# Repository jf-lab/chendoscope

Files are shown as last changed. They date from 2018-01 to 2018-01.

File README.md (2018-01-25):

# CHEndoscope Overview

Complete instructions on how to use the CHEndoscope, including assembly, surgery, behavioural protocols and data analysis can be in the [CHEndoscope protocols paper](https://www.biorxiv.org/content/early/2018/01/24/252205).

1. [Assembling your CHEndoscope](#assembling-your-chendoscope)
2. [Acquiring images with your CHEndoscope](#acquiring-images-with-your-chendoscope) 
	- [Installing acquisition code](#installation)
	- [Running the acquisition software](#running-the-acquisition-software)

3. Analysis of calcium imaging videos uses [CHEndoscope-minipipe](https://github.com/jf-lab/chendoscope-minipipe)

# Assembling your CHEndoscope
The CHEndoscope consists of 4 plastic components that can be 3D printed

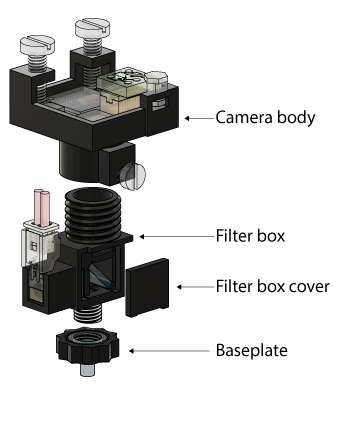
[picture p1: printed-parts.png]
3D printed components of the CHEndoscope


When printing these parts, we recommend a print resolution of at most 100μm (50μm works best in our hands). Our lab has experimented with various FDM, SLA and material jetting printers, and find that SLA printers such as the Formlabs Form2 render best results. FDM printers often lack the resolution required to render the fine threads and internal details of several CHEndoscope parts. In addition to print resolution, make sure the material you are printing with does not fluoresce or otherwise interfere with the imaging path when exposed to 470nm or 535nm light.

Download CHEndoscope [STL files](./STLs) for 3D printing, or [STEP files](./STEP-files) if you want to modify the base CHEndoscope design.

# Acquiring images with your CHEndoscope

In order to capture images from the CHEndoscope, you will need to install acquisition software that interfaces with the CHEndoscope's Ximea USB camera. This code is compatible with Linux and Windows systems.

## Installation 

[For Windows](acquisition-install-windows.md)

## Running the acquisition software

1. Open a new cmd window
    - `cd [path for storing video files]`
    - `python "path\to\vid.py"`

2. To change gains/exposure etc:
    - Open a second cmd window and run 
		`ncat -u 127.0.0.1 6557`
    - Then type for example:
		`[set_gain 10]`

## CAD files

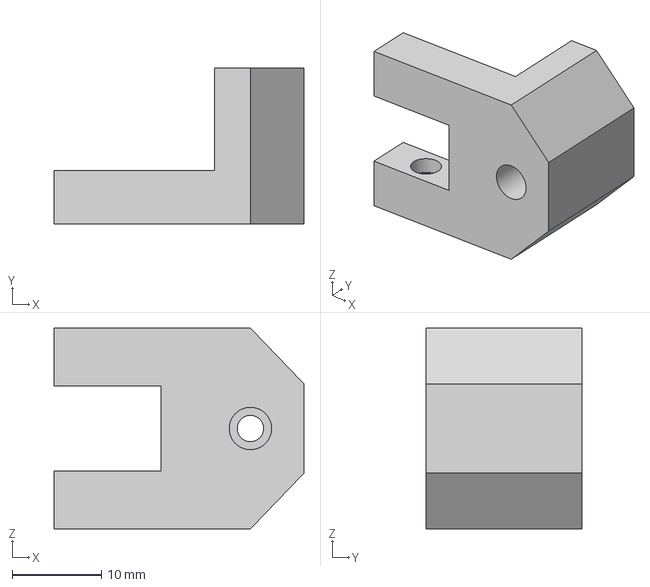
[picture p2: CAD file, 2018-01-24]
STEP-files/Stereotax clamp.step
28.0 x 17.5 x 22.5 mm

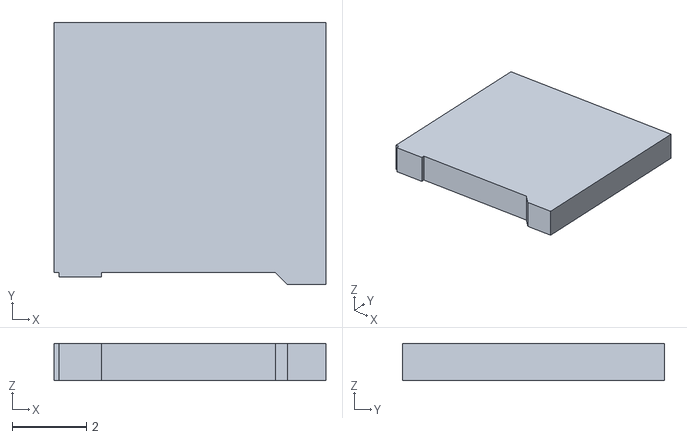
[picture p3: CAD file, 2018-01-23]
STLs/Filter box cover.stl
7.35 x 7.07 x 1.00

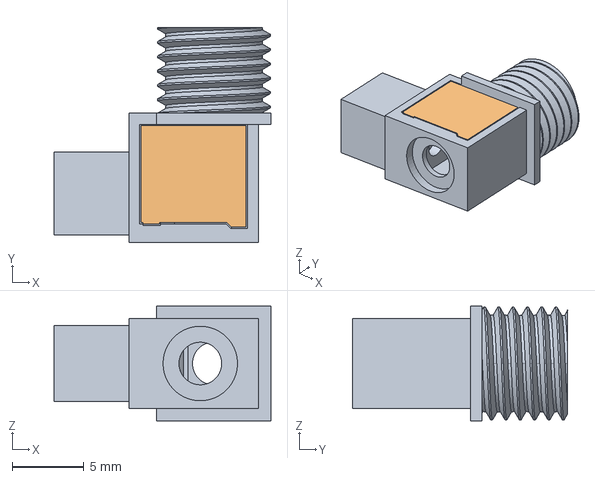
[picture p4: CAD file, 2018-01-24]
STEP-files/Filter box.step
15.2 x 15.0 x 8.00 mm

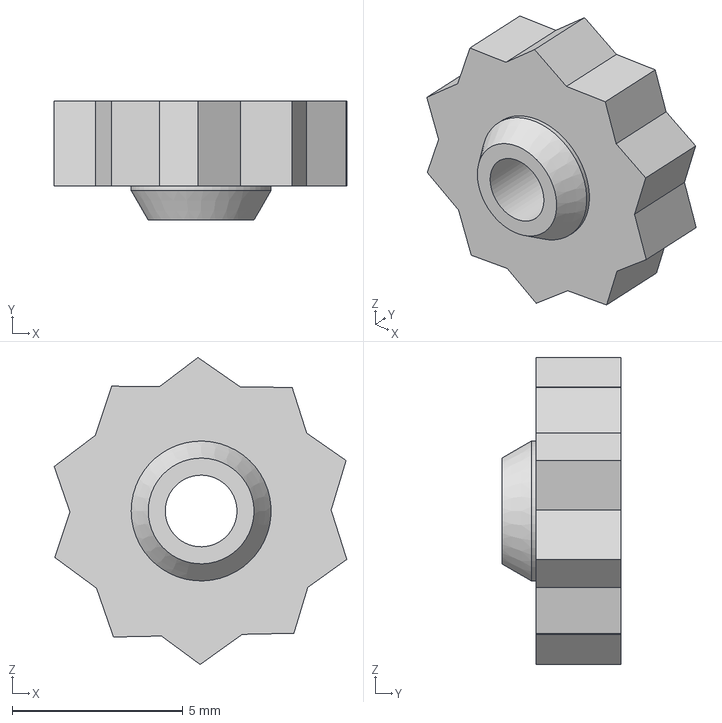
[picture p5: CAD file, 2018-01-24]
STEP-files/Baseplate.step
8.58 x 3.50 x 9.00 mm

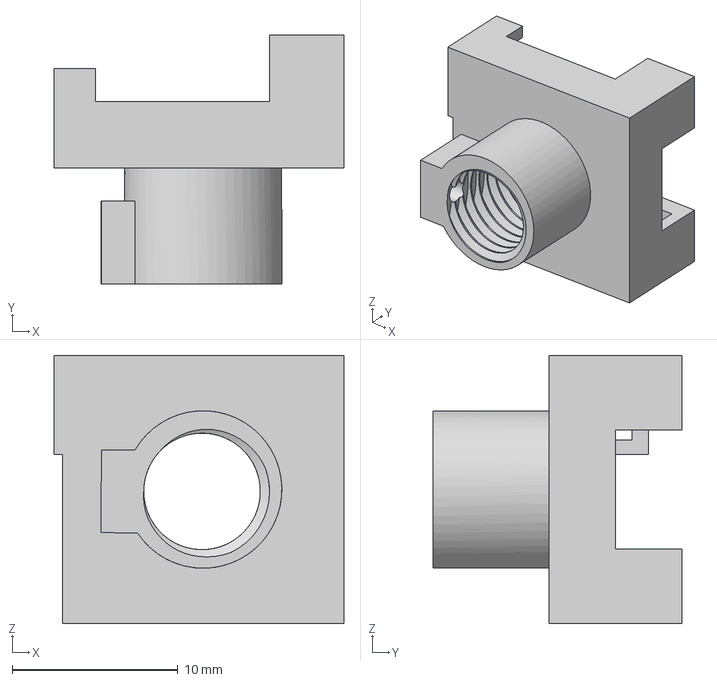
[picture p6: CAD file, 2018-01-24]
STEP-files/Camera body.step
17.5 x 15.0 x 16.2 mm

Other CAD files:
STLs/Baseplate.stl
STLs/Camera body.stl
STLs/Filter box.stl
STLs/Stereotax clamp.stl

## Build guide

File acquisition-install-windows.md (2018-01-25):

## Installation (Windows)

**Dependencies:**

- Python 3.5
  - numpy
  - scipy

1. Install opencv
	- Go to "http://www.lfd.uci.edu/~gohlke/pythonlibs/#opencv", download "opencv_python‑3.2.0+contrib‑cp35‑cp35m‑win_amd64.whl"
	- In a command line, run 
		`pip install "path\to\file\opencv_python‑3.2.0+contrib‑cp35‑cp35m‑win_amd64.whl`

2. Install XIMEA driver - https://www.ximea.com/downloads/recent/XIMEA_Installer.exe

3. Install python bindings for XIMEA driver
	- Download "https://github.com/cyanut/pyximea/raw/master/dist/pyximea-0.0.2-cp35-cp35m-win_amd64.whl"
	- In a command line, run
		`pip install "path\to\file\pyximea-0.0.2-cp35-cp35m-win_amd64.whl"`

4. Test that everything works
	- In a command line, run
		`python -i`
	- then run
		`import numpy,scipy,cv2,pyximea`
	-> python should not complain about any errors

5. Download CHEndoscope acquisition code
	- Download [vid.py](./vid.py) from this repo
	- extract the code to a directory 

6. Download ffmpeg
	- Go to "https://ffmpeg.zeranoe.com/builds/", choose a stable version, 64-bit, static, then download
	- extract the three executable files in the "bin" directory to a new directory

7. Add ffmpeg directory to system path
	- In the windows search bar, type "environment", open the "Edit system environment variable" dialog
	- Click "environment variables ..."
	- In the new dialog, select the "Path" variable, click on "edit"
	- Put in the path for ffmpeg
8. Test ffmpeg installation
	- In a command line, type `ffmpeg`. It should show a bunch of stuff but not complain about unable to find "ffmpeg"

9. Install nmap (to communicate with the recorder for changing gain, exposure etc.)
	- https://nmap.org/download.html#windows, download a stable version
	- During install, make sure the "NCat" and "Register system path" are selected

10. Install VLC (for video playback)

Installation complete!

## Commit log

2018-01-23 Added main CHEndoscope 3D files
    Upload of STEP and STL files for baseplate, camera body and filter box + cover
    [Baseplate P1.0.step, Baseplate P1.0.stl, Camera body P1.0.step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]
2018-01-24 Uploaded stereotax arm files
    [Stereotax clamp P1.0.step, Stereotax clamp P1.0.stl]
2018-01-24 Updated names and file architecture
    [Baseplate P1.0.step, Baseplate.step, Baseplate.stl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]
2018-01-24 Added printed parts figure
2018-02-02 Added PCB files for camera interface PCB
    [camera-interface-board.kicad_pcb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]
2018-02-20 Updated naming
    [camera-interface-board.kicad_pcb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]
